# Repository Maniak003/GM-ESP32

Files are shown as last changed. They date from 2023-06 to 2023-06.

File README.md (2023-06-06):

<!DOCTYPE html>
<html lang="en" data-color-mode="auto" data-light-theme="light" data-dark-theme="dark">
  <head>
    <meta charset="utf-8">
  </head>
    <body class="logged-in env-production page-responsive page-blob" style="word-wrap: break-word;">
      <p> GM counter on ESP32. </p>
      <a href="https://github.com/Maniak003/GM-ESP32/wiki" rel="nofollow">
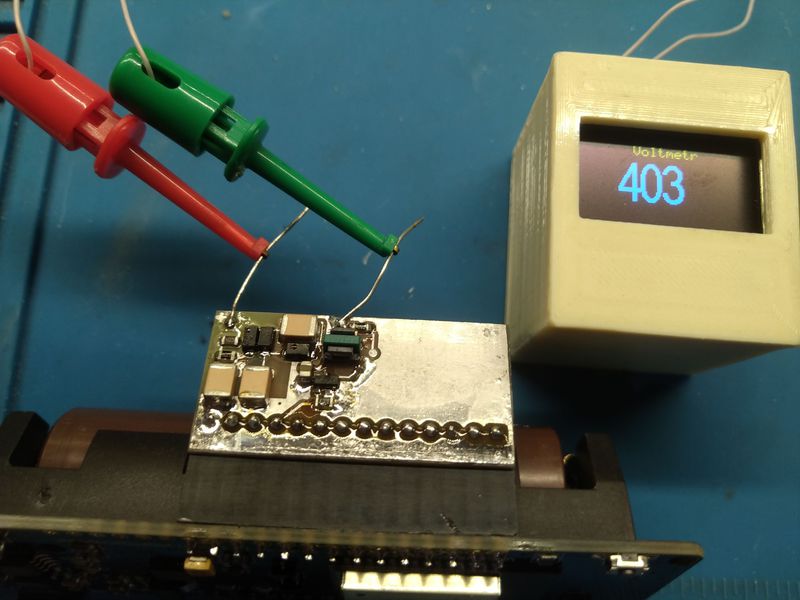
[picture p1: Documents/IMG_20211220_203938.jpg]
GM-ESP32
        
      </a>
    </body>
</html>

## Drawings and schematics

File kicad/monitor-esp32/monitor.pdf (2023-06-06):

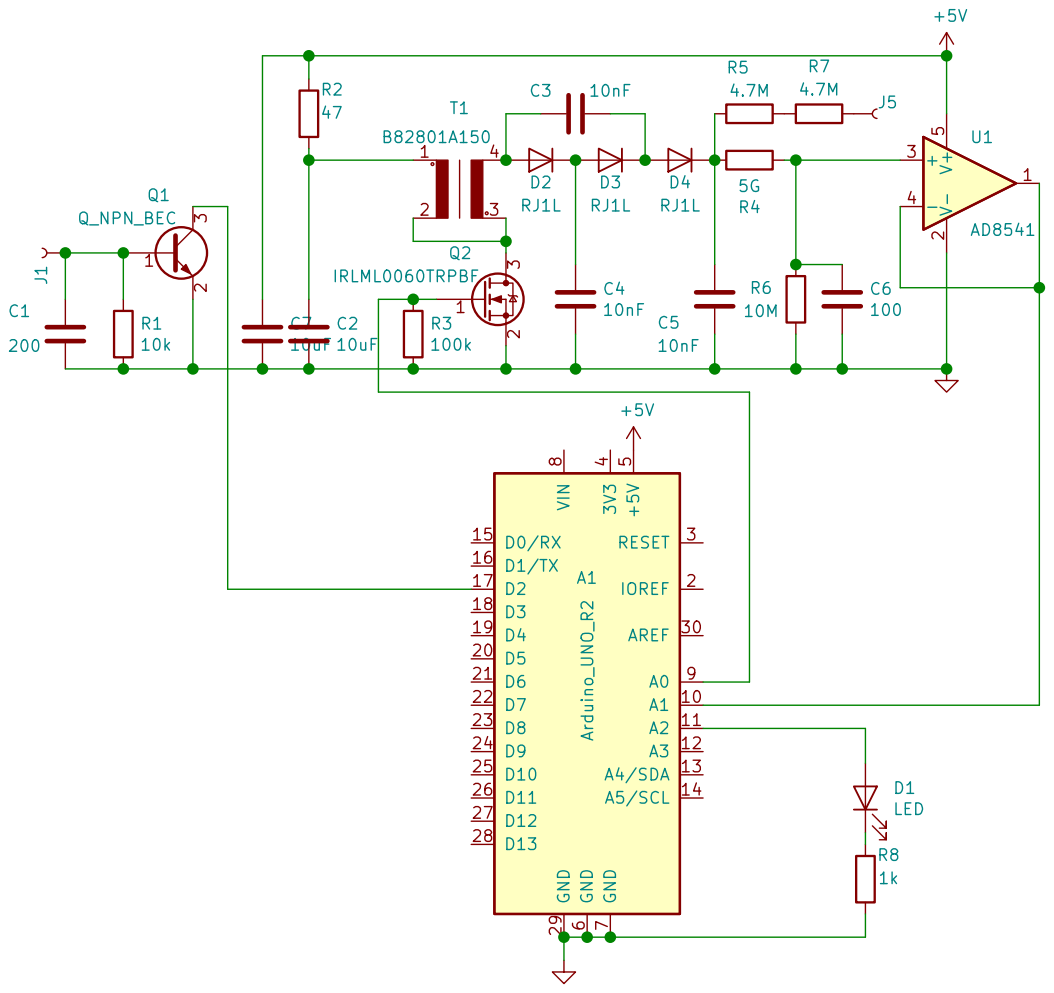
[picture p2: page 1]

Id: 1/1 Title: File: monitor.sch Sheet: /

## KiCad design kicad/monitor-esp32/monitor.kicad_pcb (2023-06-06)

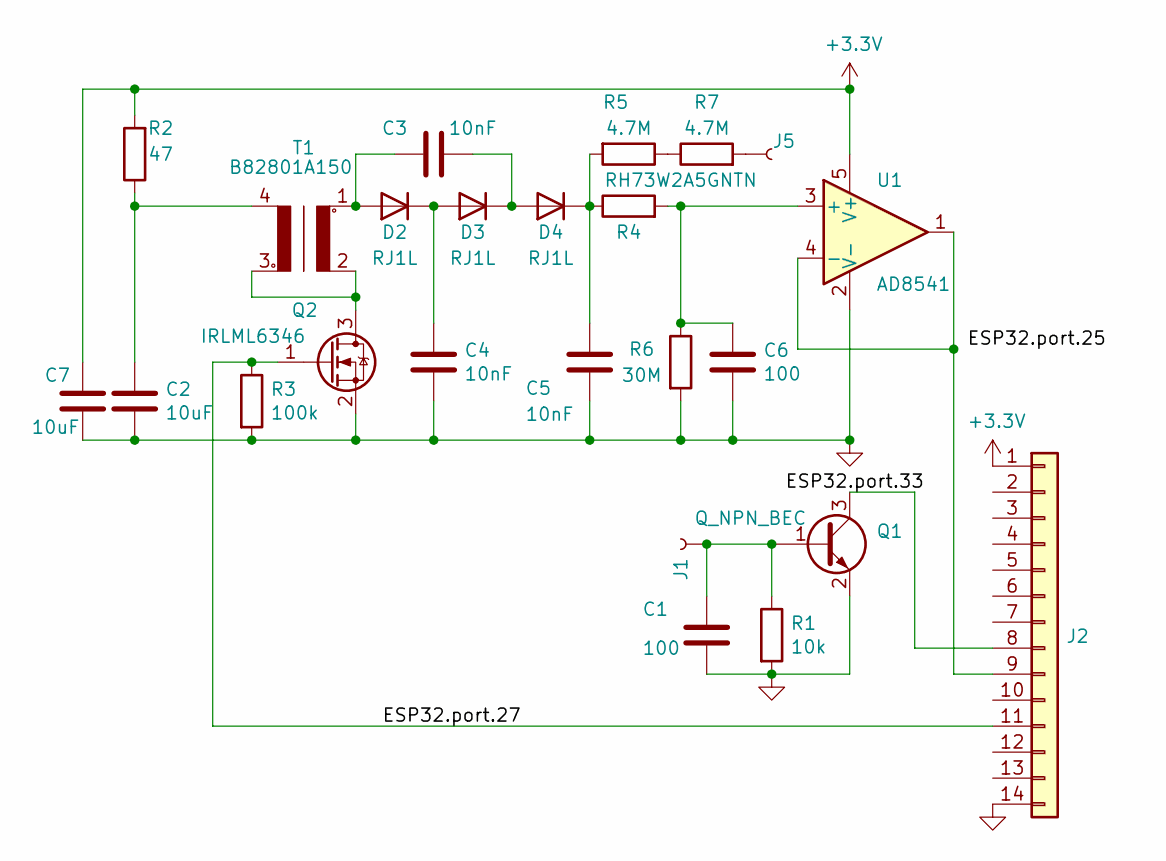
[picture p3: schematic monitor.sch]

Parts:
C1, C6: 100; C_0805_2012Metric
C2, C7: 10uF; C_0805_2012Metric
C3, C4, C5: 10nF; C_1812_4532Metric
D2, D3, D4: RJ1L; D_SOD-123
J1, J5: Conn; SMD-CONN
J2: Conn_01x14; PinHeader_1x14_P2.54mm_Horizontal
Q1: Q_NPN_BEC; SOT-23
Q2: IRLML6346; SOT-23
R1: 10k; R_0805_2012Metric
R2: 47; R_0805_2012Metric
R3: 100k; R_0805_2012Metric
R4: RH73W2A5GNTN; R_1206_3216Metric
R5, R7: 4.7M; R_0805_2012Metric
R6: 30M; R_0805_2012Metric
T1: B82801A150; B82801A1
U1: AD8541; TSOT-23-5

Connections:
+3V3: C7.1, J2.1, R2.2, U1.5 (V+)
/ESP32.port.27: J2.11, Q2.1 (G), R3.1
GND: C1.2, C2.2, C4.2, C5.2, C6.2, C7.2, J2.14, Q1.2 (E), Q2.2 (S), R1.2, R3.2, R6.2, U1.2 (V-)
unnamed: C1.1, J1.1, Q1.1 (B), R1.1
unnamed: C2.1, R2.1, T1.4
unnamed: C3.1, D3.1 (K), D4.2 (A)
unnamed: C3.2, D2.2 (A), T1.1
unnamed: C4.1, D2.1 (K), D3.2 (A)
unnamed: C5.1, D4.1 (K), R4.1, R5.2
unnamed: C6.1, R4.2, R6.1, U1.3 (+)
unnamed: J2.8, Q1.3 (C)
unnamed: J2.9, U1.1, U1.4 (-)
unnamed: J5.1, R7.2
unnamed: Q2.3 (D), T1.2, T1.3
unnamed: R5.1, R7.1

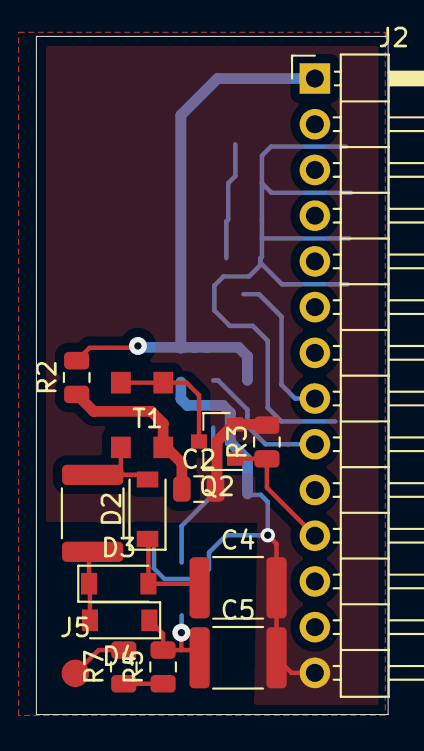
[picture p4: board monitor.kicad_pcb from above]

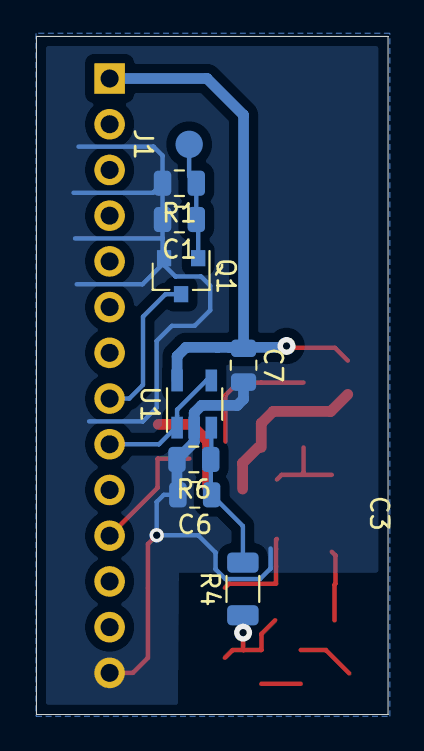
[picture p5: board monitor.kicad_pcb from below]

Board: 2 copper layers, 19.5 x 37.7 mm, 24 parts (9 on the bottom side), 15 nets.

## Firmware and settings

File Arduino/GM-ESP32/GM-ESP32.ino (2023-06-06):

#define SERIALON
#define LED 16
#define PULSEPIN 27
#define ANALOGOS 25
#define COUNTER 33
#define SENDTIME 2000
#define LEDTIME 20
#define PULSETIME 5
/* (400v ÷ (5G + 30M) × 30M) × (4096 ÷ 3.3v) */
#define VOLTAGE 2961

unsigned long tm, pulse_tm, led_tm, tm_tmp, cnt = 0, old_cnt, summ_interval = 0;
uint16_t OS, pulse2sec = 0;

void countPulse() {
  summ_interval = summ_interval + (millis() - led_tm);
  led_tm = millis();
  digitalWrite(LED, LOW);
  cnt++;
}

void setup() {
  pinMode(LED, OUTPUT);
  digitalWrite(LED, HIGH);
  pinMode(PULSEPIN, OUTPUT);
  digitalWrite(PULSEPIN, LOW);
  pinMode(ANALOGOS, INPUT);
  pinMode(COUNTER, INPUT_PULLUP);
  #ifdef SERIALON
  Serial.begin(115200);
  #endif
  attachInterrupt(COUNTER, countPulse, RISING);
  tm = millis();
  led_tm = tm;
}

void loop() {
  tm_tmp = millis();
  if (tm + SENDTIME < tm_tmp) {
    pulse2sec = cnt - old_cnt;
    old_cnt = cnt;
    tm = tm_tmp;
    #ifdef SERIALON
    Serial.print("CNT: ");
    Serial.print(cnt);
    Serial.print(" SUMM_INTERVAL: ");
    Serial.print(summ_interval);
    Serial.print(" now: ");
    Serial.println((float) ((1000.0 * cnt)/summ_interval) * 5);
    #endif
  }
  if (led_tm + LEDTIME < tm_tmp) {
    digitalWrite(LED, HIGH);
  }
  if (pulse_tm + PULSETIME < tm_tmp) {
    pulse_tm = tm_tmp;
    OS = analogRead(ANALOGOS);
    if (OS < (uint16_t) VOLTAGE) {
      noInterrupts();
      digitalWrite(PULSEPIN, HIGH);
      digitalWrite(PULSEPIN, LOW);
      interrupts();
    }
  }
}

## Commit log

2023-06-06 новый файл: kicad/monitor-esp32/fp-info-cache новый файл: kicad/monitor-esp32/monitor-cache.lib новый файл: kicad/monitor-esp32/monitor-rescue.dcm новый файл: kicad/monitor-esp32/monitor-rescue.lib н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
    [monitor.kicad_pcb, monitor.sch]
2023-06-06 новый файл: Arduino/GM-ESP32/GM-ESP32.ino
2023-06-06 новый файл: Documents/IMG_20211220_203938.jpg изменено: README.md
2023-06-06 изменено: kicad/monitor-esp32/monitor-cache.lib изменено: kicad/monitor-esp32/monitor.kicad_pcb изменено: kicad/monitor-esp32/monitor.kicad_pcb-bak изменено: kicad/monitor-esp32/monitor.sch изменено: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
    [monitor.kicad_pcb, monitor.sch]
2023-06-06 новый файл: Documents/Kamaya_RHC.pdf новый файл: Documents/NG_DS_1773268_A-721582.pdf новый файл: Documents/Ohmite.pdf
2023-06-06 изменено: kicad/monitor-esp32/monitor.sch изменено: kicad/monitor-esp32/monitor.sch-bak
    [monitor.sch]
